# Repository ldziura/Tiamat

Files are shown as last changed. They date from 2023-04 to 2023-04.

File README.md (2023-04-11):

# Tiamat

The idea behind the Tiamat project is to provide a simple, easy to use, and ergonomic gaming keyboard.
For the moment the project is in a very early stage, but it is already possible to use it.
To spice things up, the Tiamat has an integrated display that doubles as the microcontroller.

<picture>
   <source media="(prefers-color-scheme: light)" srcset="https://github.com/Mqxx/GitHub-Markdown/blob/main/blockquotes/badge/light-theme/warning.svg">
   Warning
</picture><br>

| This is still a very early prototype and the files are constantly changing. It is best to use this repository as a reference instead of a ready to use project. |
|-----------------------------------------------------------------------------------------------------------------------------------------------------------------|

## Features

#### Keyboard features : 

- Ortholinear layout
- Anti Ghosting
- Collumn stagger of the modifier to accomodate for the pinkie
- Thumb cluster for the most used keys
- Smaller spacebar for a better ergonomics
- Stacked numbers and symbols rows for an easier access
- Only the most commonly used keys for gaming
- Hotswap sockets for MX switches

- 240x240 Pin Badge LCD display with backlight that doubles as the microcontroller
- Hotswap sockets for the display

#### Firmware features :

- CircuitPython based firmware
- KMK
- Highly customizable

## Gallery

( All the keys are not final )

<p align="center" width="100%">
    
</p>

<p align="center" width="100%">
    
</p>

<p align="center" width="100%">
    
</p>

## Pin Display

### Polar coordinate snake Game

Complete Snake minigame that uses the polar coordinate system to make the best of the rounded display
Featuring :

- Completely autonomous game, no need to connect the keyboard to a computer only a power source ( you will still need to connect to the Tiamat or another keyboard to play)
- Multiple working menus
- Leaderboard and a highscore system ( stored on the display )
- Screenshot system ( stored on the display )
- And much more ! 

**Click to see on YouTube**
<p align="center" width="100%">
    <a href="https://youtu.be/_snwv8szKXo" target="_blank">
     Mt. Choc Glitch Effect
    </a>
</p>

### Animated Wolf

Logo with toggleable animation 

<p align="center" width="100%">
    
</p>

### Gyroscope controlled balls

Gyroscope controlled balls that will are physically simulated and collide with each other as well as the display borders

<p align="center" width="100%">
    
</p>

## Hardware

**WIP**

Display : https://www.waveshare.com/wiki/RP2040-LCD-1.28

## Build

**SOON**

## Firmware

**SOON**

## Credits

- Heavily inspired by Sonal Pinto and his [Mt-Choc](https://github.com/SonalPinto/mt-choc) project and all the ressources he provided
- Aedile for his [CircuitPython Implementation](https://github.com/aedile/circuit_python_wsRP2040128) of the Waveshare RP2040-LCD-1.28 that helped me a lot

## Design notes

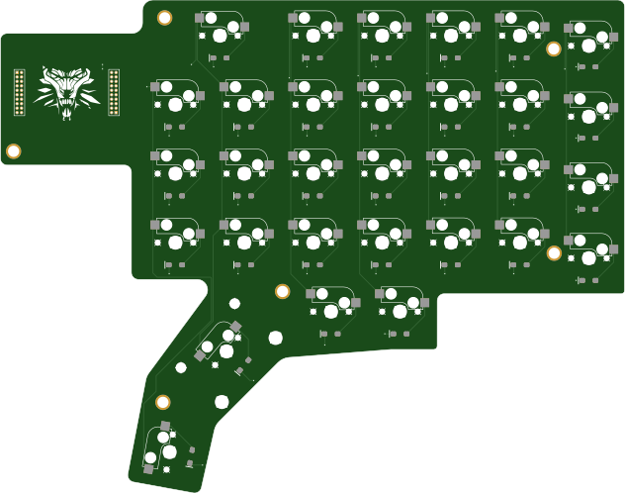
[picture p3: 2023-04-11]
00_PCB_files/Image_render/00_bottom.png

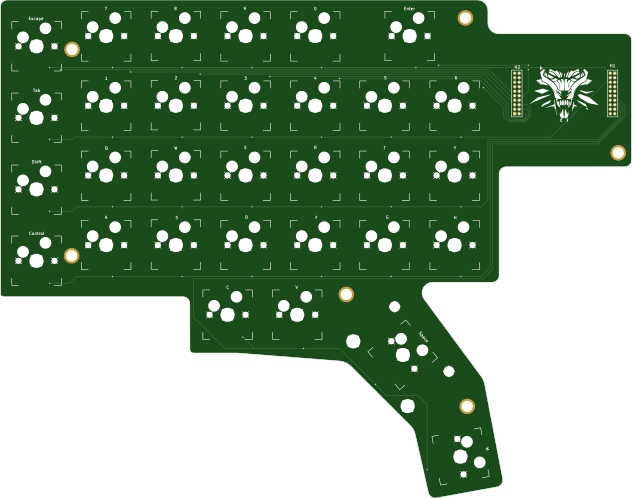
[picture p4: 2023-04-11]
00_PCB_files/Image_render/00_top.png

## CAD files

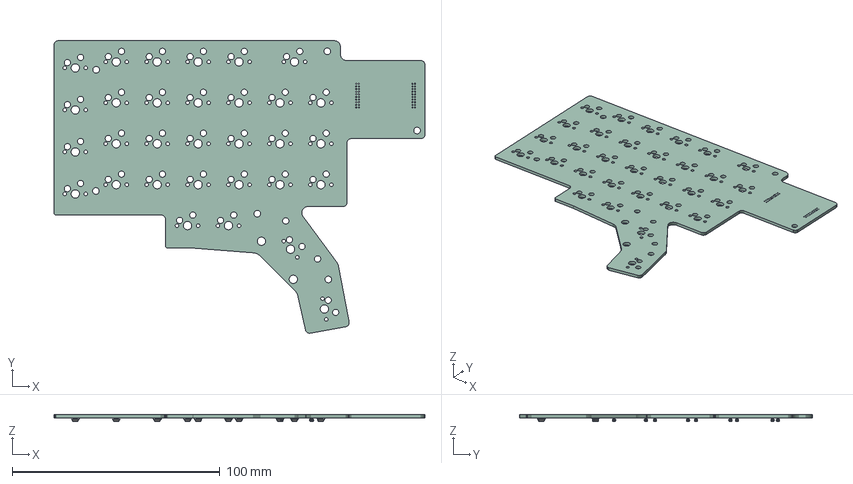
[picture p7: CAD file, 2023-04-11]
00_PCB_files/Step_file/Tiamat_v01_badge.step
178.4 x 140.7 x 3.20 mm
PCB

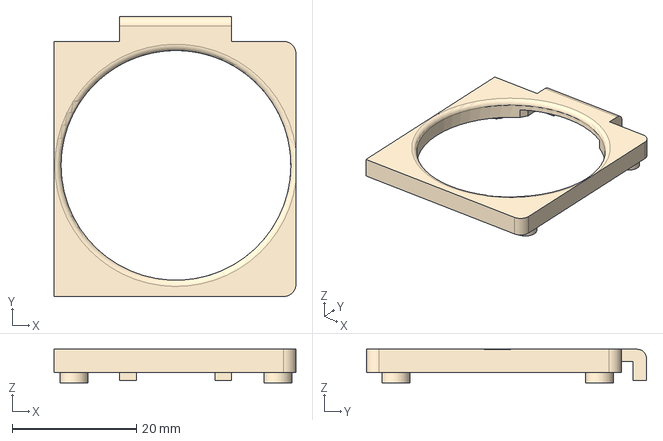
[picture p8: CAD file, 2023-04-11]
02_Case_files/Case_STEP/LCD_Case_Cover.step
39.0 x 45.1 x 5.40 mm

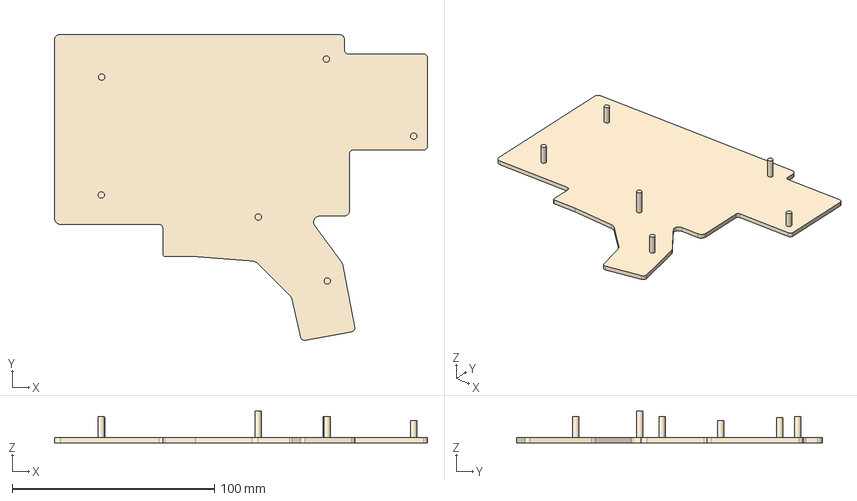
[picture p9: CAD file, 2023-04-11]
02_Case_files/Case_STEP/Lower_case.step
184.4 x 151.1 x 15.6 mm

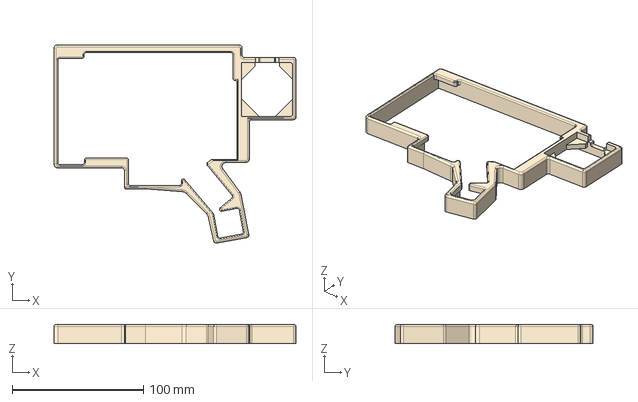
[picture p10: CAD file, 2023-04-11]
02_Case_files/Case_STEP/Upper_Case.step
184.4 x 151.1 x 14.5 mm

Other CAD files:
02_Case_files/Case_Export/LCD_Case_Cover.f3d

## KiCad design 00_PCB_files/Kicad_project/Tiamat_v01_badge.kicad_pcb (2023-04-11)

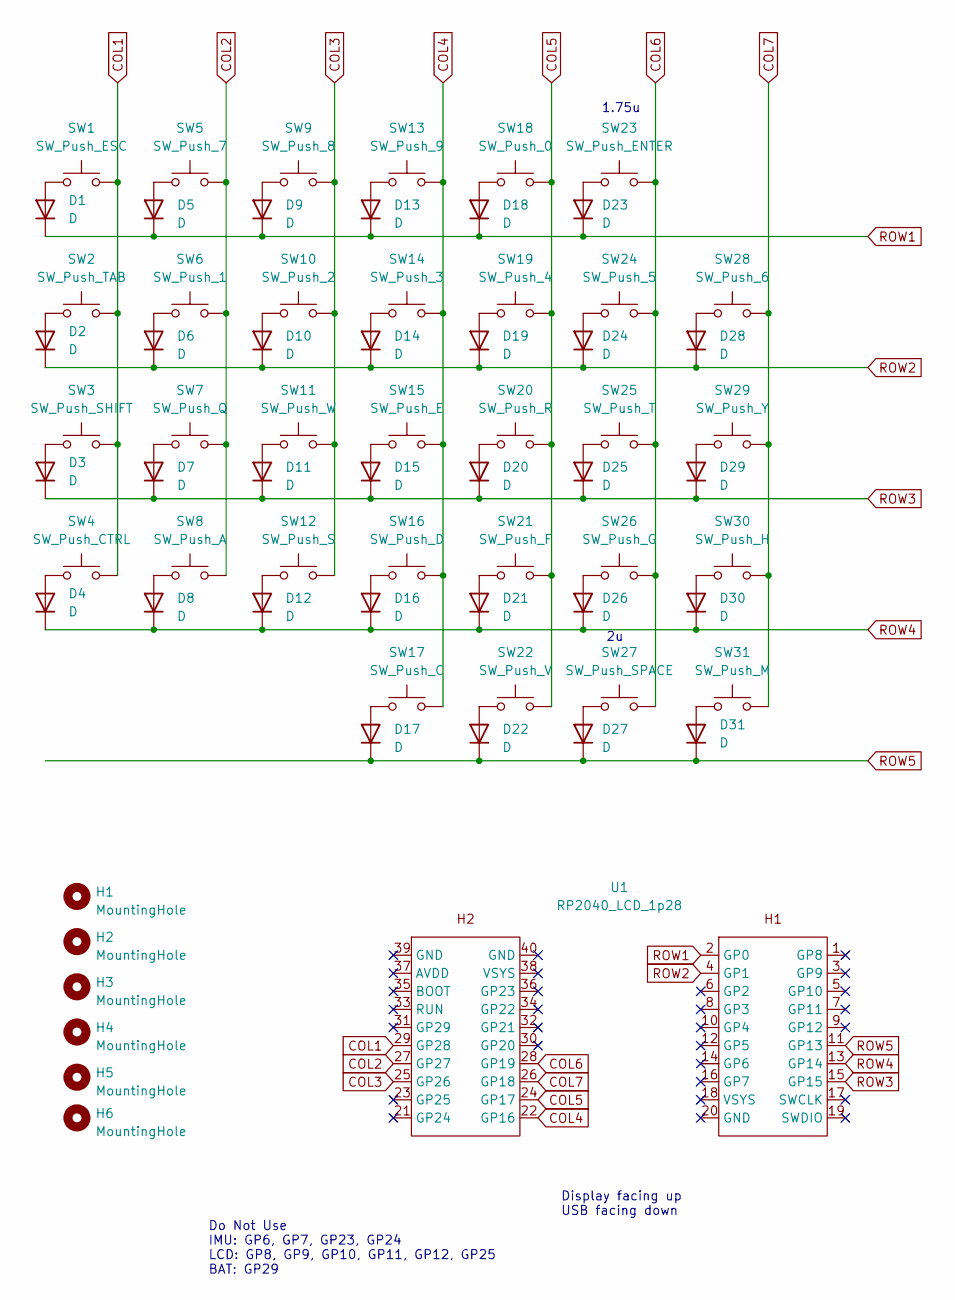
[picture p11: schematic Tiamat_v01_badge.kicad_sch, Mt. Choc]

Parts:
D1, D2, D3, D4, D5, D6, D7, D8, D9, D10, D11, D12, D13, D14, D15, D16, D17, D18, D19, D20, D21, D22, D23, D24, D25, D26, D27, D28, D29, D30, D31: D; D_SOD123
H1, H2, H3, H4, H5, H6: MountingHole; m2_standoff
SW1: SW_Push_ESC; MXOnly-1U-Hotswap
SW2: SW_Push_TAB; MXOnly-1U-Hotswap
SW3: SW_Push_SHIFT; MXOnly-1U-Hotswap
SW4: SW_Push_CTRL; MXOnly-1U-Hotswap
SW5: SW_Push_7; MXOnly-1U-Hotswap
SW6: SW_Push_1; MXOnly-1U-Hotswap
SW7: SW_Push_Q; MXOnly-1U-Hotswap
SW8: SW_Push_A; MXOnly-1U-Hotswap
SW9: SW_Push_8; MXOnly-1U-Hotswap
SW10: SW_Push_2; MXOnly-1U-Hotswap
SW11: SW_Push_W; MXOnly-1U-Hotswap
SW12: SW_Push_S; MXOnly-1U-Hotswap
SW13: SW_Push_9; MXOnly-1U-Hotswap
SW14: SW_Push_3; MXOnly-1U-Hotswap
SW15: SW_Push_E; MXOnly-1U-Hotswap
SW16: SW_Push_D; MXOnly-1U-Hotswap
SW17: SW_Push_C; MXOnly-1U-Hotswap
SW18: SW_Push_0; MXOnly-1U-Hotswap
SW19: SW_Push_4; MXOnly-1U-Hotswap
SW20: SW_Push_R; MXOnly-1U-Hotswap
SW21: SW_Push_F; MXOnly-1U-Hotswap
SW22: SW_Push_V; MXOnly-1U-Hotswap
SW23: SW_Push_ENTER; MXOnly-1.75U-Hotswap
SW24: SW_Push_5; MXOnly-1U-Hotswap
SW25: SW_Push_T; MXOnly-1U-Hotswap
SW26: SW_Push_G; MXOnly-1U-Hotswap
SW27: SW_Push_SPACE; MXOnly-2U-Hotswap
SW28: SW_Push_6; MXOnly-1U-Hotswap
SW29: SW_Push_Y; MXOnly-1U-Hotswap
SW30: SW_Push_H; MXOnly-1U-Hotswap
SW31: SW_Push_M; MXOnly-1U-Hotswap
U1: RP2040_LCD_1p28

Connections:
COL1: SW1.2, SW2.2, SW3.2, SW4.2, U1.29 (GP28)
COL2: SW5.2, SW6.2, SW7.2, SW8.2, U1.27 (GP27)
COL3: SW9.2, SW10.2, SW11.2, SW12.2, U1.25 (GP26)
COL4: SW13.2, SW14.2, SW15.2, SW16.2, SW17.2, U1.22 (GP16)
COL5: SW18.2, SW19.2, SW20.2, SW21.2, SW22.2, U1.24 (GP17)
COL6: SW23.2, SW24.2, SW25.2, SW26.2, SW27.2, U1.28 (GP19)
COL7: SW28.2, SW29.2, SW30.2, SW31.2, U1.26 (GP18)
unnamed: D1.2 (A), SW1.1
unnamed: D2.2 (A), SW2.1
unnamed: D3.2 (A), SW3.1
unnamed: D4.2 (A), SW4.1
unnamed: D5.2 (A), SW5.1
unnamed: D6.2 (A), SW6.1
unnamed: D7.2 (A), SW7.1
unnamed: D8.2 (A), SW8.1
unnamed: D9.2 (A), SW9.1
unnamed: D10.2 (A), SW10.1
unnamed: D11.2 (A), SW11.1
unnamed: D12.2 (A), SW12.1
unnamed: D13.2 (A), SW13.1
unnamed: D14.2 (A), SW14.1
unnamed: D15.2 (A), SW15.1
unnamed: D16.2 (A), SW16.1
unnamed: D17.2 (A), SW17.1
unnamed: D18.2 (A), SW18.1
unnamed: D19.2 (A), SW19.1
unnamed: D20.2 (A), SW20.1
unnamed: D21.2 (A), SW21.1
unnamed: D22.2 (A), SW22.1
unnamed: D23.2 (A), SW23.1
unnamed: D24.2 (A), SW24.1
unnamed: D25.2 (A), SW25.1
unnamed: D26.2 (A), SW26.1
unnamed: D27.2 (A), SW27.1
unnamed: D28.2 (A), SW28.1
unnamed: D29.2 (A), SW29.1
unnamed: D30.2 (A), SW30.1
unnamed: D31.2 (A), SW31.1
ROW1: D1.1 (K), D5.1 (K), D9.1 (K), D13.1 (K), D18.1 (K), D23.1 (K), U1.2 (GP0)
ROW2: D2.1 (K), D6.1 (K), D10.1 (K), D14.1 (K), D19.1 (K), D24.1 (K), D28.1 (K), U1.4 (GP1)
ROW3: D3.1 (K), D7.1 (K), D11.1 (K), D15.1 (K), D20.1 (K), D25.1 (K), D29.1 (K), U1.15 (GP15)
ROW4: D4.1 (K), D8.1 (K), D12.1 (K), D16.1 (K), D21.1 (K), D26.1 (K), D30.1 (K), U1.13 (GP14)
ROW5: D17.1 (K), D22.1 (K), D27.1 (K), D31.1 (K), U1.11 (GP13)

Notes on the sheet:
Do Not Use IMU: GP6, GP7, GP23, GP24 LCD: GP8, GP9, GP10, GP11, GP12, GP25 BAT: GP29
1.75u
Display facing up USB facing down

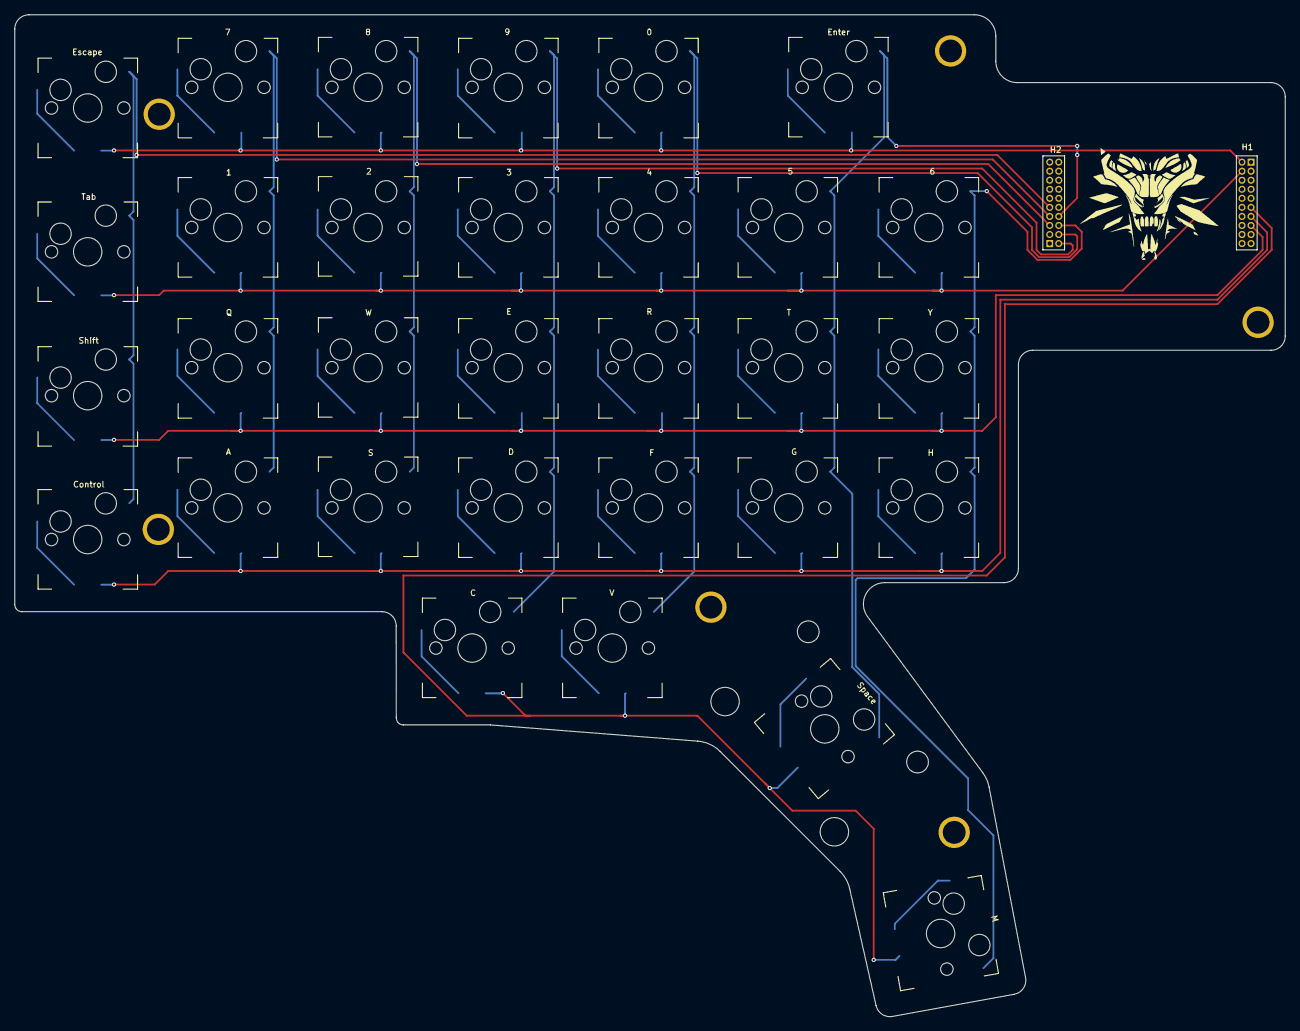
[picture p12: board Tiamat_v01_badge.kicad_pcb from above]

Board: 2 copper layers, 178.4 x 140.7 mm, 69 parts (0 on the bottom side), 43 nets.

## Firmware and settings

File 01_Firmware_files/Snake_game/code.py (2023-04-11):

"""
Mt Choc v1.0 KMK Build
"""

import board
import busio
import displayio
import adafruit_imageload

from kmk.kmk_keyboard import KMKKeyboard
from kmk.keys import KC, make_key
from kmk.scanners import DiodeOrientation
from kmk.modules.layers import Layers
from kmk.modules.combos import Combos, Chord, Sequence
from kmk.handlers.sequences import send_string
from display import Display



class MtChoc(KMKKeyboard):
    def __init__(self):
        # =============================================================
        # Scanner
        self.diode_orientation = DiodeOrientation.COL2ROW

        self.col_pins = (
            board.GP28,     # col-1 (left)
            board.GP27,
            board.GP26,
            board.GP16,
            board.GP17,
            board.GP19,
            board.GP18,     # col-16 (right)

        )

        self.row_pins = (
            board.GP0,      # row-1 (top)
            board.GP1,
            board.GP15,
            board.GP14,
            board.GP13,     # row-5 (bottom)
        )

        # =============================================================
        # Physical Layout
        self.coord_mapping = [
            0,  1,  2,  3,  4,  5, 6,
            7,  8,  9, 10, 11, 12, 13,
            14, 15, 16, 17, 18, 19, 20,
            21, 22, 23, 24, 25, 26, 27,
            28, 29, 30, 31, 32, 33, 34,
        ]

        # =============================================================
        # Extensions
        layer_ext = Layers()
        display_ext = Display()

        # Combos
        combos = Combos()

        make_key(names=('MOVEUP',),on_press=lambda *args: display_ext.move_up(),)
        make_key(names=('MOVEDOWN',),on_press=lambda *args: display_ext.move_down(),)
        make_key(names=('MOVELEFT',),on_press=lambda *args: display_ext.move_left(),)
        make_key(names=('MOVERIGHT',),on_press=lambda *args: display_ext.move_right(),)
        make_key(names=('SELECT',),on_press=lambda *args: display_ext.select(),)
        make_key(names=('SCREENSHOT',),on_press=lambda *args: display_ext.screenshot(),)
        make_key(names=('TEST',),on_press=lambda *args: display_ext.create_body(),)


        combos.combos = [
        Chord((KC.N2, KC.W), KC.MOVEUP),
        Chord((KC.S, KC.W), KC.MOVEDOWN),
        Chord((KC.Q, KC.W), KC.MOVELEFT),
        Chord((KC.E, KC.W), KC.MOVERIGHT),
        Chord((KC.ENT, KC.SPC), KC.SELECT),
        Chord((KC.C, KC.V), KC.SCREENSHOT),
        Chord((KC.N7, KC.N8), KC.TEST),
        ]

        self.modules = [layer_ext, display_ext, combos]
        # =============================================================
        # Keymap
        _______ = KC.TRNS
        XXXXXXX = KC.NO

        # Layers
        LOWER = KC.MO(1)
        RAISE = KC.MO(2)

        self.keymap = [
            [   # Base
                KC.ESC,     KC.N7,    KC.N8,    KC.N9,    KC.N0,    KC.ENT,   XXXXXXX,
                KC.LCTRL,   KC.N1,    KC.N2,    KC.N3,    KC.N4,    KC.N5,    KC.N6,
                KC.TAB,     KC.Q,     KC.W,     KC.E,     KC.R,     KC.T,     KC.Y,
                KC.LSFT,    KC.A,     KC.S,     KC.D,     KC.F,     KC.G,     KC.H,
                XXXXXXX,    XXXXXXX,  XXXXXXX,   KC.C,     KC.V,     KC.SPC,   KC.M
            ],
            [   # Lower
                KC.GRV,   _______, _______,   _______,  _______,  _______,
                _______,  _______, _______,   _______,  _______,  _______,  _______,
                _______,  _______, _______,   _______,  _______,  _______,  _______,
                _______,  _______, _______,   _______,  _______,  _______,  _______,
                _______,  _______, _______,   _______,
            ],
            [   # Raise
                KC.TILD,  _______, _______,   _______,  _______,  _______,
                _______,  _______, _______,   _______,  _______,  _______,  _______,
                _______,  _______, _______,   _______,  _______,  _______,  _______,
                _______,  _______, _______,   _______,  _______,  _______,  _______,
                _______,  _______, _______,   _______,
            ],
        ]


if __name__ == '__main__':

    print("loading kmk and badge display")

    keyboard = MtChoc()
    keyboard.go()

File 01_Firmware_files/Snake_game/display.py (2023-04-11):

import time
import board
import random
import gc
import busio
import displayio
import adafruit_imageload
import random
import math
import terminalio
import json


from adafruit_display_shapes.circle import Circle
from adafruit_display_shapes.roundrect import RoundRect
from adafruit_display_text import label

from adafruit_bitmapsaver import save_pixels
import storage

from kmk.extensions import Extension

big_circle_pos = [120, 120]  # Position of the bigger circle (center of the screen)
big_circle_radius = 125


def distance(point1, point2):
    return math.sqrt((point1[0] - point2[0]) ** 2 + (point1[1] - point2[1]) ** 2)

def cartesian_to_polar(x, y):
    r = math.sqrt(x * x + y * y)
    theta = math.atan2(y, x)
    return r, theta

def polar_to_cartesian(r, theta):
    """
    /!\ The angle is in radians /!\\
    """

    x = r * math.cos(theta)
    y = r * math.sin(theta)
    return x, y

def color_palette(colstr):

    colors = {
        'black': 0x000000,
        'white': 0xFFFFFF,
        'gray': 0x808080,
        'lightgray': 0xC0C0C0,
        'darkgray': 0x404040,
        'red': 0xFF0000,
        'green': 0x00FF00,
        'blue': 0x0000FF,
        'yellow': 0xFFFF00,
        'cyan': 0x00FFFF,
        'magenta': 0xFF00FF,
        'orange': 0xFFA500,
        'purple': 0x800080,
        'brown': 0xA52A2A,
        'pink': 0xFFC0CB,
        'lime': 0x00FF00,
        'teal': 0x008080,
        'maroon': 0x800000,
        'navy': 0x000080,
        'olive': 0x808000,
        'violet': 0xEE82EE,
        'turquoise': 0x40E0D0,
        'silver': 0xC0C0C0,
        'gold': 0xFFD700,
        'indigo': 0x4B0082,
        'coral': 0xFF7F50,
        'salmon': 0xFA8072,
        'tan': 0xD2B48C,
        'khaki': 0xF0E68C,
        'plum': 0xDDA0DD,
        'darkgreen': 0x006400
    }
    try:
        return colors[colstr]
    except:
        return [0x000000]

def star_points(center, num_points, outer_radius, inner_radius, rotation):
    points = []
    angle = math.pi / num_points
    for i in range(num_points * 2):
        radius = inner_radius if i % 2 == 0 else outer_radius
        current_angle = i * angle + math.radians(rotation)
        x = math.ceil(center[0] + math.cos(current_angle) * radius)
        y = math.ceil(center[1] + math.sin(current_angle) * radius)
        points.append((x, y))
    return points


class GameManager:

    def __init__(self, sprite_sheet, sprite_palette, title_sheet, title_palette):

        self.container_group = displayio.Group()

        self.title_spritesheet = title_sheet
        self.title_palette = title_palette

        self.sprite_sheet = sprite_sheet
        self.palette = sprite_palette


        # ===GAME START MENU===#

        self.game_start_menu_is_displayed = True


        self.start_menu_label_pos = {"Start": [120, 120], "Controls" : [120, 150], "Rules" : [120, 180]}
        self.start_menu_label_padding = {"Start": 50, "Controls": 70, "Rules": 50}
        self.start_menu_label_order = ["Start", "Controls", "Rules"]
        self.start_menu_label_gfx = {"Start": None, "Controls": None, "Rules": None}

        self.current_game_start_selected_text = "Start"

        #create start label
        self.start_label = label.Label(font=terminalio.FONT, text="Start", color=color_palette("gold"),
                                       x=self.start_menu_label_pos["Start"][0],
                                       y=self.start_menu_label_pos["Start"][1],
                                       anchor_point=(0.5, 0.5),
                                       anchored_position=(self.start_menu_label_pos["Start"][0], self.start_menu_label_pos["Start"][1]),
                                       scale=2)



        self.controls_label = label.Label(font=terminalio.FONT, text="Controls", color=color_palette("gold"),
                                          x=self.start_menu_label_pos["Controls"][0],
                                          y=self.start_menu_label_pos["Controls"][1],
                                          anchor_point=(0.5, 0.5),
                                          anchored_position=(self.start_menu_label_pos["Controls"][0], self.start_menu_label_pos["Controls"][1]),
                                          scale=2)

        # self.controls_label_gfx = displayio.TileGrid(self.sprite_sheet, pixel_shader=self.palette, width=1, height=1, tile_height=16, tile_width=16)
        # self.controls_label_gfx[0] = 9
        # self.controls_label_gfx.x = self.start_menu_label_pos["Controls"][0] - self.start_menu_label_padding["Controls"]
        # self.controls_label_gfx.y = self.start_menu_label_pos["Controls"][1] - 8

        self.rules_label = label.Label(font=terminalio.FONT, text="Rules", color=color_palette("gold"),
                                       x=self.start_menu_label_pos["Rules"][0],
                                       y=self.start_menu_label_pos["Rules"][1],
                                       anchor_point=(0.5, 0.5),
                                       anchored_position=(self.start_menu_label_pos["Rules"][0], self.start_menu_label_pos["Rules"][1]),
                                       scale=2)

        # self.rules_label_gfx = displayio.TileGrid(self.sprite_sheet, pixel_shader=self.palette, width=1, height=1, tile_height=16, tile_width=16)
        # self.rules_label_gfx[0] = 9
        # self.rules_label_gfx.x = self.start_menu_label_pos["Rules"][0] - self.start_menu_label_padding["Rules"]
        # self.rules_label_gfx.y = self.start_menu_label_pos["Rules"][1] - 8


        self.snake_title = displayio.TileGrid(self.title_spritesheet, pixel_shader=self.title_palette, width=5, height=1, tile_height=16, tile_width=16)
        self.snake_title[0] = 0
        self.snake_title[1] = 1
        self.snake_title[2] = 2
        self.snake_title[3] = 3
        self.snake_title[4] = 4

        self.snake_title.x = 20
        self.snake_title.y = 20

        self.start_menu = displayio.Group(scale=1)

        self.snake_title_group = displayio.Group(scale=2)
        self.snake_title_group.append(self.snake_title)

        self.start_menu.append(self.snake_title_group)

        self.start_menu.append(self.start_label)
        # self.start_menu.append(self.start_label_gfx)

        self.start_menu.append(self.controls_label)
        # self.start_menu.append(self.controls_label_gfx)

        self.start_menu.append(self.rules_label)
        # self.start_menu.append(self.rules_label_gfx)

        # self.container_group.append(self.start_menu)




        #===GRAPHICS===#

        self.sprite_sheet = sprite_sheet
        self.palette = sprite_palette

        #create a sprite
        self.fruit_gfx = displayio.TileGrid(self.sprite_sheet, pixel_shader=self.palette, width=1, height=1, tile_height=16, tile_width=16)
        self.fruit_gfx[0] = 6

        #===SCORE MANAGEMENT===#

        self.score = 0
        self.score_pos = [120, 120]
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

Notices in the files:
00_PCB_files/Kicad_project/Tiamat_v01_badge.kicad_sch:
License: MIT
